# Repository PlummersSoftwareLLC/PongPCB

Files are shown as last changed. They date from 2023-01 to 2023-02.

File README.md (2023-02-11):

# PongPCB
This is a KiCad project and Gerber files for Pong Composite Video replacement PCB, as featured in the original [Dave's Garage episode](https://youtu.be/iF7lo0vU_WI).

How PONG Works: From Schematic to PCB to Console (https://youtu.be/iF7lo0vU_WI)

In theory you should be able to order a board from JLCPCB using just the Gerber files (specifically, the already-packed 'Archive.zip' in the Gerbers folder). 
Or you could use KiCad to load the project and generate your own Gerber and Drill files.

A list of the components that need to be soldered onto the PCB is included in [PARTSLIST.md](PARTSLIST.md). A list of other components is included in the video description on YouTube.

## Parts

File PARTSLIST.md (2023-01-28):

# Parts list

Below is the list of components that need to be installed onto the PCB, as indicated on the PCB design. A list of (other) components with purchase links is already available in the [YouTube video](https://youtu.be/iF7lo0vU_WI) description. The links in the table below are to reference information only.

| Category | Value/type | Quantity | Board location(s) | Notes |
|-|-|-|-|-|
| Capacitor | 30pF | 2 | C1, C2 | |
| Capacitor | 0.1&#181;F | 2 | C3, C4 | |
| Crystal oscillator | HC49U 2.0MHz, or equivalent | 1 | Y1 | Oscillators are available in a wide range of frequencies, make sure to get the 2.0 MHz type! |
| DC barrel power connector | horizontal | 2 | J1, J4 | |
| IC | [AY-3-8500](https://en.wikipedia.org/wiki/AY-3-8500) | 1 | U1 | Has to be taken from the Coleco Telstar PCB, or another system that's based on it. If sockets are used, this IC must not be soldered but inserted into the socket after that has been soldered in. |
| IC | DIL-14 [4001](https://en.wikibooks.org/wiki/Practical_Electronics/IC/4001) | 1 | U3 | Can be taken from the Coleco Telstar PCB. If buying separately, note that a surface-mount version (SOIC-14) is also available that won't work for this build. If sockets are used, this IC must not be soldered but inserted into the socket after that has been soldered in. |
| IC | DIL-14 [4072](https://en.wikibooks.org/wiki/Practical_Electronics/IC/4072) | 1 | U2 | Can be taken from the Coleco Telstar PCB. If buying separately, note that a surface-mount version (SOIC-14) is also available that won't work for this build. If sockets are used, this IC must not be soldered but inserted into the socket after that has been soldered in. |
| Pin header | 2 pins | 1 | J5 | |
| Pin header | 14 pins | 1 | J2 | |
| RCA connector | RCJ-044 | 1 | J3 | |
| Resistor | 47&#8486; | 1 | R12 | |
| Resistor | 75&#8486; | 1 | R6 | |
| Resistor | 220&#8486; | 4 | R2, R5, R8, R9 | |
| Resistor | 330&#8486; | 1 | R10 | |
| Resistor | 510&#8486; | 2 | R3, R11 | |
| Resistor | 10K&#8486; | 2 | R4, R7 | |
| Resistor | 12M&#8486; | 1 | R1 | |
| Socket | 14 pins | 2 | U2, U3 | Use of sockets is recommended, but strictly speaking optional. |
| Socket | 28 pins | 1 | U1 | Use of sockets is recommended, but strictly speaking optional. |
| Transistor | [2N3904](https://en.wikipedia.org/wiki/2N3904) | 1 | Q1 | |

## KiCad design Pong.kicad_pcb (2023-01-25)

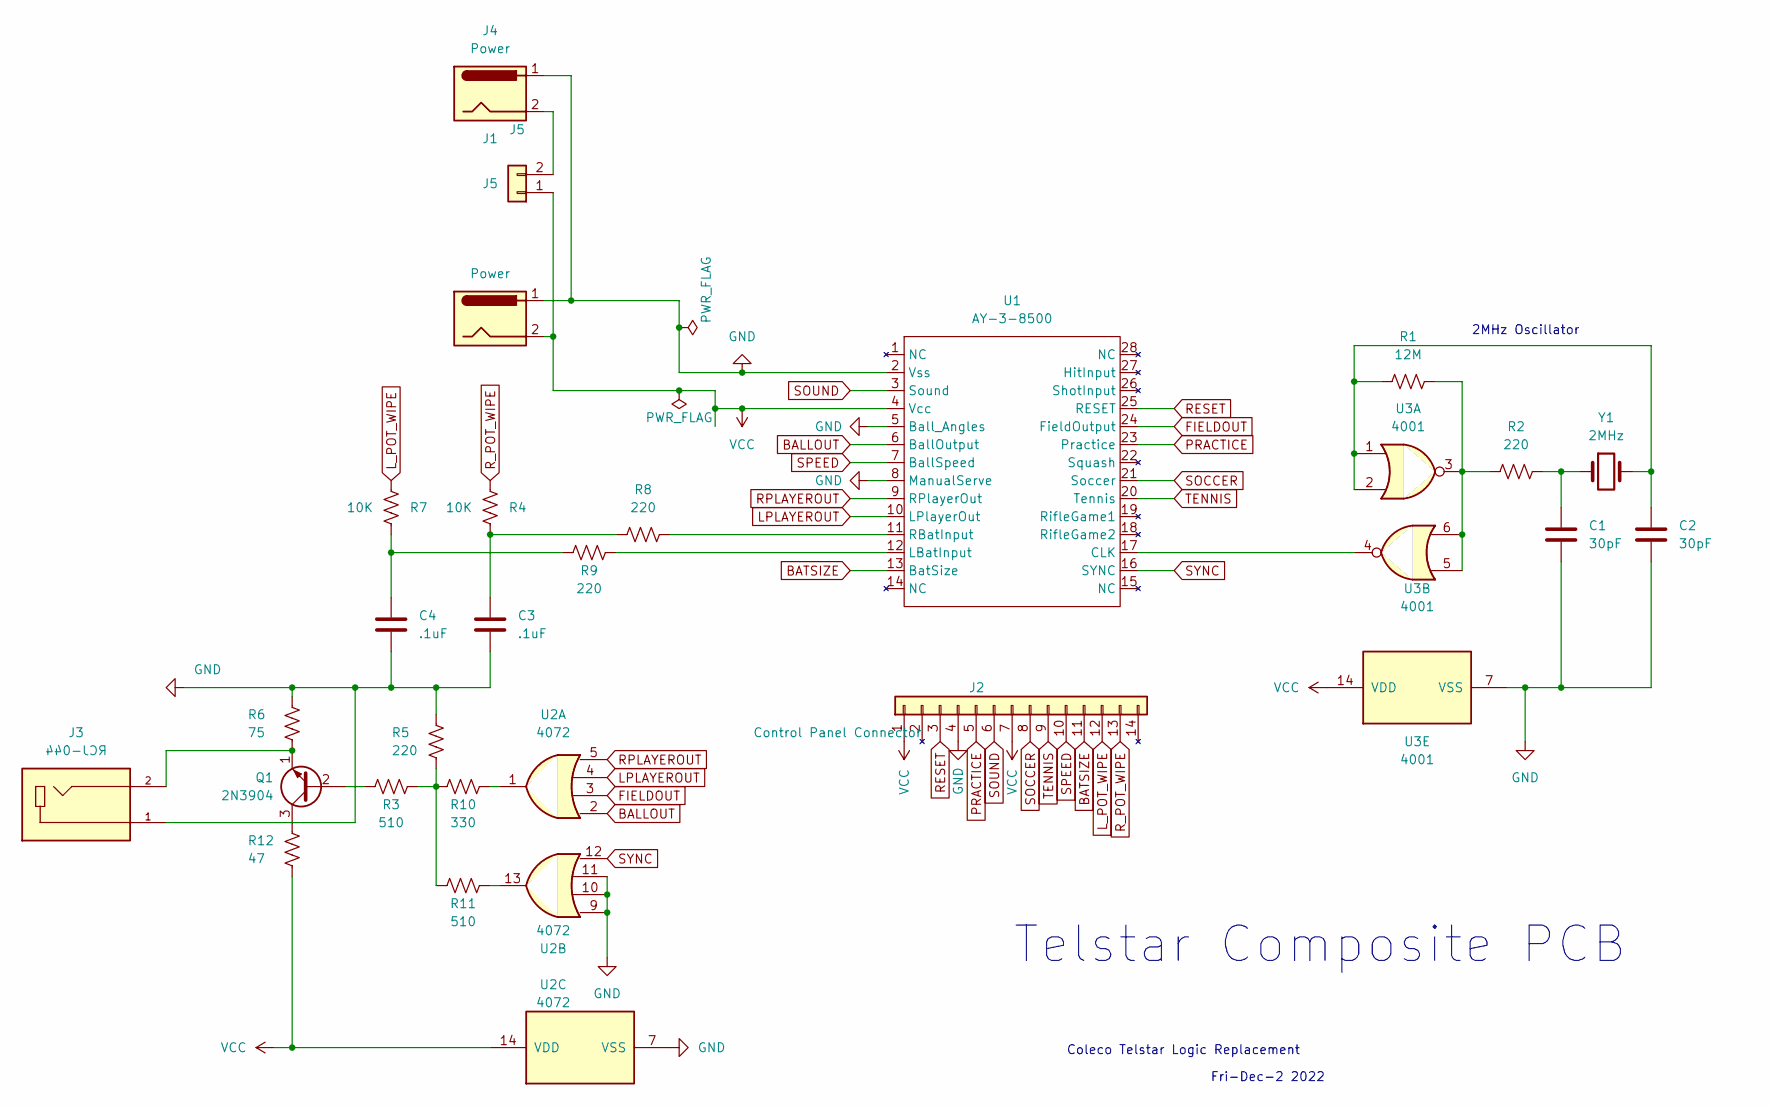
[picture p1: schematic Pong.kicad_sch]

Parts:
C1, C2: 30pF; C_Disc_D8.0mm_W5.0mm_P7.50mm
C3, C4: .1uF; C_Disc_D8.0mm_W5.0mm_P7.50mm
J1, J4: Power; BarrelJack_CUI_PJ-063AH_Horizontal
J2: Control Panel Connector; Molex_KK-254_AE-6410-14A_1x14_P2.54mm_Vertical
J3: RCJ-044; CUI_RCJ-044; PARTREV 1.02
J5: J5; PinHeader_1x02_P1.27mm_Horizontal
Q1: 2N3904; TO-92_Inline
R1: 12M; R_Axial_DIN0309_L9.0mm_D3.2mm_P12.70mm_Horizontal
R2, R5, R8, R9: 220; R_Axial_DIN0309_L9.0mm_D3.2mm_P12.70mm_Horizontal
R3, R11: 510; R_Axial_DIN0309_L9.0mm_D3.2mm_P12.70mm_Horizontal
R4, R7: 10K; R_Axial_DIN0309_L9.0mm_D3.2mm_P12.70mm_Horizontal
R6: 75; R_Axial_DIN0309_L9.0mm_D3.2mm_P12.70mm_Horizontal
R10: 330; R_Axial_DIN0309_L9.0mm_D3.2mm_P12.70mm_Horizontal
R12: 47; R_Axial_DIN0309_L9.0mm_D3.2mm_P12.70mm_Horizontal
U1: AY-3-8500; DIP-28_W15.24mm_Socket_LongPads
U2: 4072; DIP-14_W7.62mm_Socket_LongPads
U3: 4001; DIP-14_W7.62mm_Socket_LongPads
Y1: 2MHz; Crystal_HC52-8mm_Horizontal

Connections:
BALLOUT: U1.6 (BallOutput), U2.2
BATSIZE: J2.11, U1.13 (BatSize)
FIELDOUT: U1.24 (FieldOutput), U2.3
GND: C1.2, C2.2, C3.2, C4.2, J1.1, J2.4, J3.1, J4.1, R5.1, R6.1, U1.2 (Vss), U1.5 (Ball_Angles), U1.8 (ManualServe), U2.7 (VSS), U2.9, U2.10, U2.11, U3.7 (VSS)
LPLAYEROUT: U1.10 (LPlayerOut), U2.4
L_POT_WIPE: J2.12, R7.1
unnamed: C1.1, R2.2, Y1.1
unnamed: C2.1, R1.1, U3.1, U3.2, Y1.2
unnamed: C4.1, R7.2, R9.1
unnamed: J3.2, Q1.1 (E), R6.2
unnamed: J4.2, J5.2
unnamed: Q1.2 (B), R3.1
unnamed: Q1.3 (C), R12.1
unnamed: R1.2, R2.1, U3.3, U3.5, U3.6
unnamed: C3.1, R4.2, R8.1
unnamed: R8.2, U1.11 (RBatInput)
unnamed: R9.2, U1.12 (LBatInput)
unnamed: R3.2, R5.2, R10.1, R11.1
unnamed: R10.2, U2.1
unnamed: R11.2, U2.13
unnamed: U1.17 (CLK), U3.4
PRACTICE: J2.5, U1.23 (Practice)
RESET: J2.3, U1.25 (RESET)
RPLAYEROUT: U1.9 (RPlayerOut), U2.5
R_POT_WIPE: J2.13, R4.1
SOCCER: J2.8, U1.21 (Soccer)
SOUND: J2.6, U1.3 (Sound)
SPEED: J2.10, U1.7 (BallSpeed)
SYNC: U1.16 (SYNC), U2.12
TENNIS: J2.9, U1.20 (Tennis)
VCC: J1.2, J2.1, J2.7, J5.1, R12.2, U1.4 (Vcc), U2.14 (VDD), U3.14 (VDD)

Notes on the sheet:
Coleco Telstar Logic Replacement
Fri-Dec-2 2022
2MHz Oscillator
Telstar Composite PCB

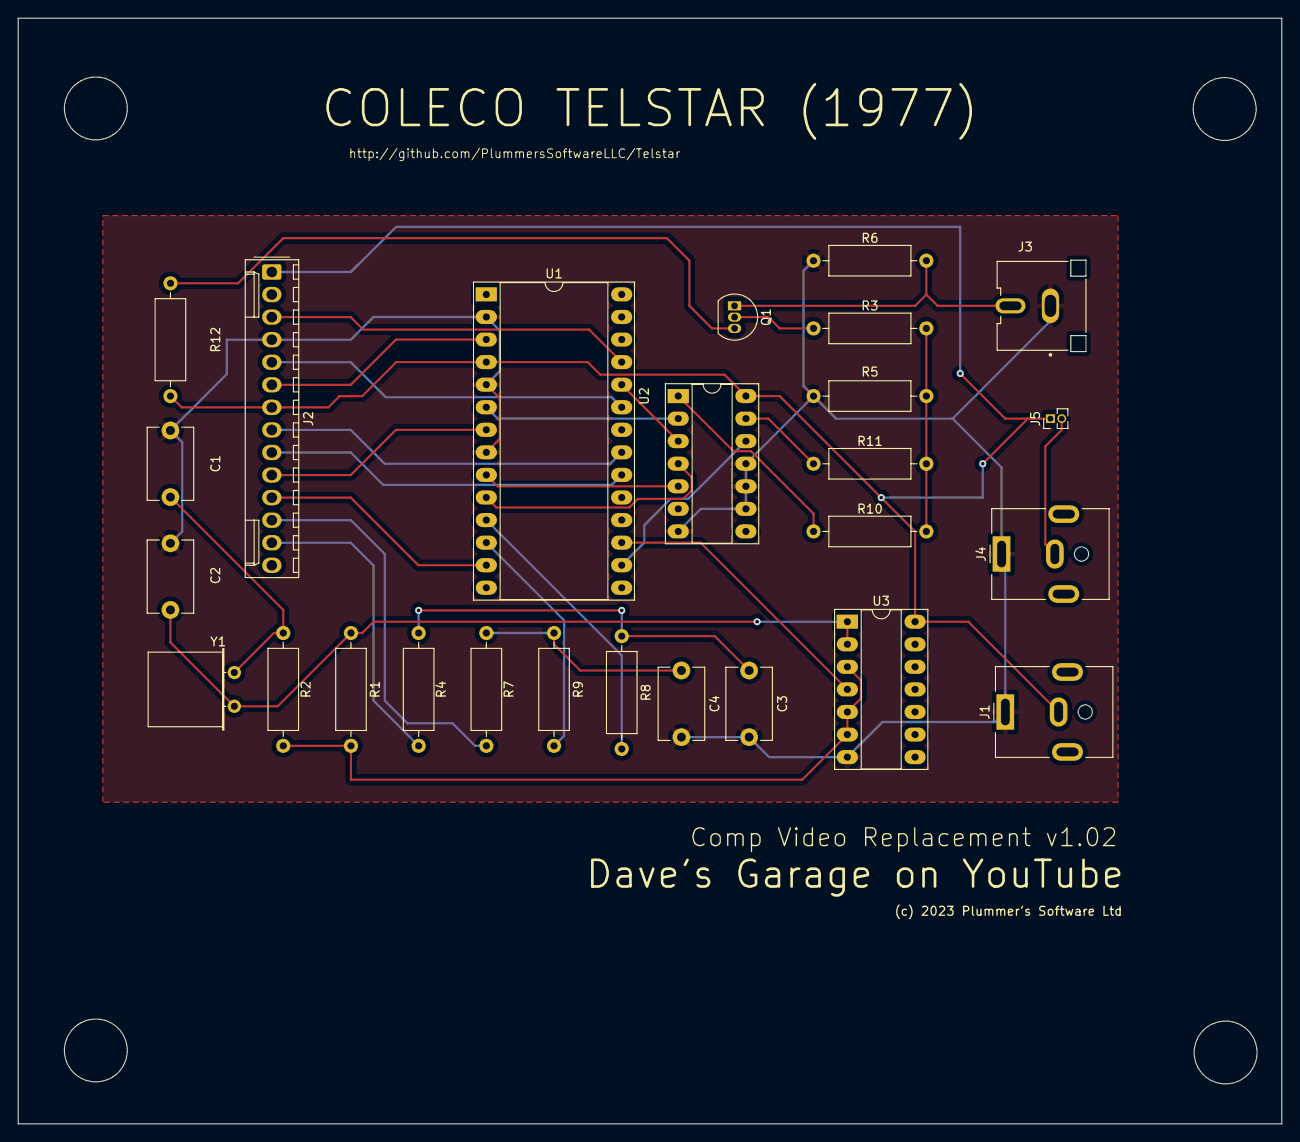
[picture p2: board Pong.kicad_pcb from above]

Board: 2 copper layers, 142.2 x 124.5 mm, 26 parts (0 on the bottom side), 31 nets.

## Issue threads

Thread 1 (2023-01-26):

Parts List

jmccusker, 2023-01-26:
Could you add a component parts list to this archive along with the links to the 3rd party parts you used to make this all work?   I'm going to try to do this and just want to be sure I have everything needed.  Great work Dave!

davepl, 2023-01-26:
The video description has a list of the more interesting parts beyond supplies, as I don’t want to populate the GitHub with affiliate links!  Of course you need a Telstar console off eBay, but as long as the main chips work, the machine itself doesn’t need to…

- Dave

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

davepl, 2023-01-27:
I just used off the shelf resistors and caps, so don’t have part numbers for those!  But the schematic does detail everything you need to collect...

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

jmccusker, 2023-01-27:
Thanks Dave,

I’ll take a look an post details of everything.  Thanks for doing this,
it’ll be a fun build for sure!

Jim

On Thu, Jan 26, 2023 at 7:17 PM David W Plummer ***@***.***>
wrote:

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

rbergen, 2023-01-27:
I agree that it would be nice to include a list of the components that are required to complete the build. For one, I think it's quite easy to miss something if the bill of materials is deduced from the silk screen on the PCB. I also think that the list would be even more useful if we explicitly indicate which components can/must be taken from the Telstar console (I think the AY-3-8500 is the only one where "must" applies, but I may well be mistaken).

@jmccusker if I correctly understand your last comment as stating that you will put a list together then I'm happy to review it. I could also put one together myself this weekend, in which case a review by someone else would be helpful.

jmccusker, 2023-01-27:
Rutger, if you have time this weekend to do it, then by all means please do
so.  I don't think I'll be able to get things pulled together for at least
another couple weeks given my schedule.  This is going to be a fun little
side-project for me and I plan to place it in my game room connected to a
big HDMI screen TV.  :-)  Should be great for some retro fun.

 --Jim

On Fri, Jan 27, 2023 at 7:43 AM Rutger van Bergen ***@***.***>
wrote:

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

rbergen, 2023-01-27:
I'll do my best, but no hard promises. There are some personal circumstances I won't bore you with that may make it not happen this weekend after all. I'll basically post the (draft) list as soon as I have it. Just to be clear: the list I create will indeed be based on reading the markings on the silk screen and some associated Googling. I don't have the hardware to put the project together available to me at the moment. In that sense the parts list will be "untested" until someone who built the project reviews it.

jmccusker, 2023-01-27:
Sounds good.  I have the parts so I can validate things and help get us a validated list.  No rush, this is hobby work and should be fun.

rbergen, 2023-01-27:
Don't worry, I'm not feeling rushed. I'm just managing expectations. :) I'll report back when I've put a first draft available.

rbergen, 2023-01-28:
Below is a list of components that need to be installed onto the PCB, as taken from the PCB design. As Dave already indicated, a list of (other) components with affiliate links is available in the video description. That's also the reference I would make in the readme. The links in the table are to reference information only.

@davepl I initially took the oscillator type from the affiliate link in the video description (MCO-1510A), but that's a 4-pin component. The PCB only has through holes for 2. The HC49U is a two-pin component that also looks like what I see in the video. Can you confirm which of the two components is the correct one to use?

| Category | Value/type | Quantity | Board location(s) | Notes |
|-|-|-|-|-|
| DC barrel power connector | horizontal | 2 | J1, J4 | |
| Capacitor | 30 pF | 2 | C1, C2 | |
| Capacitor | 0.1 &#181;F | 2 | C3, C4 | |
| Crystal oscillator | HC49U 2.0MHz, or equivalent | 1 | Y1 | Oscillators are available in a wide range of frequencies, make sure to get the 2.0 MHz type! |
| IC | [AY-3-8500](https://en.wikipedia.org/wiki/AY-3-8500) | 1 | U1 | Has to be taken from the Coleco Telstar PCB, or another system that's based on it. If sockets are used, this IC must not be soldered but inserted into the socket after that has been soldered in. |
| IC | [MOS 4001](https://en.wikibooks.org/wiki/Practical_Electronics/IC/4001) | 1 | U3 | Can be taken from the Coleco Telstar PCB. If buying separately note that a surface-mount version (SMB 4001) is also available that won't work for this build. If sockets are used, this IC must not be soldered but inserted into the socket after that has been soldered in. |
| IC | [MOS 4072](https://en.wikibooks.org/wiki/Practical_Electronics/IC/4072) | 1 | U2 | Can be taken from the Coleco Telstar PCB. If buying separately note that a surface-mount version (SMB 4072) is also available that won't work for this build. If sockets are used, this IC must not be soldered but inserted into the socket after that has been soldered in. |
| Pin header | 2 pins | 1 | J5 | |
| Pin header | 14 pins | 1 | J2 | |
| RCA connector | RCJ-044 | 1 | J3 | |
| Resistor | 47 &#8486; | 1 | R12 | |
| Resistor | 75 &#8486; | 1 | R6 | |
| Resistor | 220 &#8486; | 4 | R2, R5, R8, R9 | |
| Resistor | 330 &#8486; | 1 | R10 | |
| Resistor | 510 &#8486; | 2 | R3, R11 | |
| Resistor | 10K &#8486; | 2 | R4, R7 | |
| Resistor | 12M &#8486; | 1 | R1 | |
| Socket | 14 pins | 2 | U2, U3 | Use of sockets is recommended, but strictly speaking optional. |
| Socket | 28 pins | 1 | U1 | Use of sockets is recommended, but strictly speaking optional. |
| Transistor | [2N3904](https://en.wikipedia.org/wiki/2N3904) | 1 | Q1 | |

davepl, 2023-01-28:
Thanks so much for putting this together!  If you’re OK with it, I’ll add it to the video description as well.

The oscillator I could not find in stock anywhere, and wound up grabbing a pack of 10 off eBay.  I’m sure they must still be out there, but I couldn’t find a current 2MHz oscillator on Amazon.  Probably Digikey would be smarter :-)

- Dave

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

rbergen, 2023-01-28:
You're welcome! Of course you can use it, but if you can give me a couple of minutes I will add a partslist.md to the repo that you can link to instead. I don't think the table format will survive if you try to paste it in the YouTube video description directly. I'll post another comment here with the URL in a few minutes.

About the oscillator, the main question I have is if I'm correct that it has to be a 2-pin oscillator?

davepl, 2023-01-28:
Yup, just pasted the original in there and it’s a mess, but that might be unavoidable because I think the comments strips spaces!  Messy…

Yes, the oscillator is a 2-pin.  To be honest I don’t even know if a crystal is polarized or symmetrical, but I always put it in label up.

 -Dave

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

rbergen, 2023-01-28:
The link to the parts list in a readable form is this: https://github.com/PlummersSoftwareLLC/PongPCB/blob/main/PARTSLIST.md

rbergen, 2023-01-28:
Oh, and don't call me out on this if things do end up exploding, but I'm pretty sure 2-pin oscillators are not polarized. :)

davepl, 2023-01-28:
Done!  Thanks again!

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

jmccusker, 2023-01-29:
Well done Rutger!  I'm hoping to gather parts and get mine working again on my HDMI TV like Dave demonstrated.  Thanks!

rbergen, 2023-01-29:
You are both very welcome!

@jmccusker Please feel free to close this issue when you're sufficiently convinced that the point in question has been addressed.

tpimh, 2023-05-02:
Hi @rbergen! In your part list, you mention that SOIC-14 parts won't work for this build. Is it due to mechanical incompatibilities (footprint being much smaller, thus the IC not fitting into the socket)? Or is there something more to it?

In the first case, I believe using an adapter (like this)[https://www.cedist.com/products/pcb-smd-thru-hole-adapter-soic-14-dip-14] or even an [SMT socket](http://www.andksocket.com/sop-socket/SOP14-SOIC-14-SO14-to-DIP14-Pr.html) would solve the incompatibility.

rbergen, 2023-05-02:
Hi @tpimh. SOIC-14 parts are surface-mount parts, and this is a through-hole build. Which is something I'm sure can be overcome one way or another, but that would then require additional parts. With a straightforward parts list like this, it's simply not realistic to consider all the permutations of components that don't fit but can be coerced into working using adapters, conversion sockets, etc.

On another note, I'm going to close this issue as it's been stale for 4 months. If you want to continue this discussion, please open a topic in the Discussion section. I have just enabled that section specifically for that purpose.

Thanks!

Closed 2023-05-02.

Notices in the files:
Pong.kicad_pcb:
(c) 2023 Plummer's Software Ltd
